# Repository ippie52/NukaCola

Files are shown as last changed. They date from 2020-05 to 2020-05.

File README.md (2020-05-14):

# NukaCola

## What is this for?
This is an Arduino Nano project aimed specifically for a more exciting display of a Fallout themed decoration. The code here is customised for my display, however could easily be adapted for other displays.

I have deliberately split the code into fairly logical files, however I have not bothered extracting the code into headers and source CPP files as my aim was to get this working, not present this to a customer with all the bells and whistles.

That being said, my occupation requires I be thorough with documentation and so it heavily commented, which will hopefully help anyone wishing to adapt this code for their own projects.

There are several 'features' that I would like to fix, but currently they don't cause any breakages, so they may never be changed.

## Hardware

### Bill of materials (electronics)
This is aimed at the Arduino Nano boards, and therefore the pin mappings may not be correct if you are using another platform.
As well as an Arduino Nano, I also used:
- Arduino Nano
- 6 x 5mm UV LEDs (For illuminating the bottle)
- 6 x 220 Ohm resistors (for the UV LEDs)
- 3 x Push to make switches (for changing the illumination)
- 3 x 10k Ohm resistors (pull-downs for the inputs)
- 3 x 3mm LEDs (for showing what settings are being updated)
- 3 x 330 Ohm resistors (for the display LEDs)
- Strip board

### Stand
I have placed the STL for the stand on [thingiverse](https://www.thingiverse.com/thing:4352918). I printed this using blue glow in the dark PLA, which works rather nicely. This was printed with the bottle in mind, where the 5mm UV LEDs are mounted to fit just under the base of the bottle, are evenly spaced at 60° from one another in a circle, and angled towards the water line within the bottle (around 7° off the vertical). Once printed, I also painted the logo on the front with white Acrylic, which blocks the light when showing to keep the logo visible.

For more info on the stand, please visit the link above.

### Bottle
The bottle used was an old 330ml Coca Cola bottle with a Nuka Cola Quantum label and bottle top printed and stuck on. The contents is tonic water (quinine fluoresces under UV light), with some blue curaçao for the blue tinge.

### Pin map
| Arduino Nano Pin | Connected To | Notes |
| ----- | --- | --- |
| 3 | Display LED 1 |  Display output (5mm UV LED with 220 Ohm resistor) |
| 5 | Display LED 2 |  Display output (5mm UV LED with 220 Ohm resistor) |
| 6 | Display LED 3 |  Display output (5mm UV LED with 220 Ohm resistor) |
| 9 | Display LED 4 |  Display output (5mm UV LED with 220 Ohm resistor) |
| 10 | Display LED 5 |  Display output (5mm UV LED with 220 Ohm resistor) |
| 11 | Display LED 6 |  Display output (5mm UV LED with 220 Ohm resistor) |
| 11 | Display LED 6 |  Display output (5mm UV LED with 220 Ohm resistor) |
| 2 | Mode LED | Indicator output for 'mode' (3mm LED with 330 Ohm resistor) |
| 4 | Speed LED | Indicator output for 'speed' (3mm LED with 330 Ohm resistor) |
| 7 | Brightness LED | Indicator output for 'brightness' (3mm LED with 330 Ohm resistor) |
| 8 | Setting Input | Input for changing the current setting mode |
| 12 | Up Input | Input for incrementing the current setting value |
| 13 | Down Input | Input for decrementing the current setting value |

## Patterns and speeds
There are several [illumination patterns](https://imgur.com/gallery/nqhQovs) that provide interesting effects. To obtain these effects, the LEDs are treated as being in a circle, with the first LED in the cluster being at 0°, then each other being evenly spaced (depending on the number of LEDs). With six LEDs, they are therefore at 60° from one another, i.e. 0°, 60°, 120°, 180°, 240° and 300°.

With the concept of a circle, the speed of the illumination pattern is effectively the number of revolutions around the circle per minute, ranging from 6 (once every ten seconds) to 60 (once per second). Different patterns appear better at different speeds, so play around until you find a nice combination.

Considering the speed, the time since the LED cluster was started can therefore determine the position around the circle and the current revolution. I call this the head or lead angle.

Image of wave pattern

### Just On
This is simple. The LEDs are just on at the brightness level set.

### Chase (Clockwise, Anticlockwise and Both)
For this pattern, the lead angle will be at the maximum brightness whilst one degree behind it will be off. This means the LED closest behind the lead angle will illuminate from off to full then dim slowly. This pattern is available clockwise, (LEDs 1 to 6) or anticlockwise (6 to 1), and both, where the lead angle is mirrored around 0° and 180°, giving two lead angles.

### Wave (Clockwise and Anticlockwise)
The brightness around the lead angle ramps up and down, with 180° being fully off. This causes the brightness to move around the circle in a wave, both clockwise and anticlockwise.

### Throb
The throb is a simple cosine wave of the current lead angle, with all LEDs being at the same brightness.

### Throb Two
This is similar to the previous, however provides a double pulse. Using a sine wave that is reflected around 180° there is a ramp up, back to half brightness, the back up to full. The pulse then drops to zero, back up to half brightness, then down to zero again before repeating the pattern. I found this by accident when messing up the equation, but I liked it so left it in.

### Heartbeat
This pattern is a rough attempt to look like a heartbeat.

### Raindrop
Each LED will flash at a random time once per revolution. The flash will be a sudden ramp up with slower drop down.

### Flames
This is supposed to look like flames flickering. It's not perfect and for some reason it always ends up on the low end of brightness, but it seems good enough for the purpose!

### Static/Noise
This is based on the flames pattern, but introduces additional spikes of noise which give a much more random pattern.

## Controls
### Manual controls
If using the buttons and LEDs attached to the board, the controls are fairly self explanatory:

#### Setting Button
When pressed, this should trigger the pattern mode LED to light up. Subsequent presses will then cause the brightness then speed LEDs to light up. When these mode LED indicators are lit, they indicate that the particular setting can be updated by pressing the up or down buttons. If no buttons are pressed for over 10 seconds, they LEDs will turn off and running or sleep more will continue.

Pressing the setting button for more than 2 seconds will toggle the mode from running to sleep mode. Pressing again for a further 2 seconds will put it back into running mode.

#### Up Button
When in pattern mode, this will select the next illumination pattern. This will always trigger a change as the patterns will loop. When in brightness mode, it will increase the brightness until it reaches 100%. When in speed mode, it will increase the speed until it reaches 100%.

#### Down Button
When in pattern mode, this will select the previous illumination pattern. This will always trigger a change as the patterns will loop. When in brightness mode, it will decrease the brightness until it reaches 5% (the lowest value permitted). When in speed mode, it will decrease the speed until it reaches 10% (the lowest speed permitted).

### Serial Comms
The API for this is fairly basic, allowing for simple strings to be used to set and alter values.

#### API Query
By sending the string "api?" (or any unrecognised command), a rough guide to the API will be sent via the serial connection.

#### Pattern
The letter 'P' is used to update the illumination pattern. Sending an upper case 'P' will increment the pattern, whilst a lower case will decrement it. To set a particular pattern index, use 'p=X', where X is the pattern index (the case of the 'p' is not important here)

#### Brightness
The letter 'B' is used to update the brightness value. Like with the pattern controls, an upper case 'B' will increase the brightness, whilst a lower case 'b' will decrease the brightness. The brightness level cannot be increased or decreased below the minimum and maximum values. To set the value exactly, use 'b=XXX', where XXX is the brightness percentage.

#### Speed
The letter 'S' is used to update the speed value. Like with the pattern and brightness controls, an upper case 'S' will increase the speed, whilst a lower case 'b' will decrease the speed. The speed level cannot be increased or decreased below the minimum and maximum values. To set the value exactly, use 's=XXX', where XXX is the speed percentage.

#### Sleep mode
To turn off the LED cluster, use the command 'X' (case insensitive).

#### Running mode
To bring the LED cluster out of sleep mode, use the command 'R' (case insensitive).

## How all this came to be
The Hallowe'en before last, I went with a Fallout themed costume. Along with that, I made a glowing Nuka Cola Quantum bottle and a little stand made from some strip board, a 9 volt battery, some resistors and UV LEDs.

Since then, it's been sat above my desk gathering dust.

I recently had reason to start looking at Arduino boards, and whilst doing so, looked up and thought about my Nuka Cola Quantum bottle. I also thought about how it would be nice to have a proper stand for it, and then decided to make it a reality.

I created a stand from blue glow in the dark PLA on my 3D printer and put together an Arduino Nano board to control the UV LEDs for a more exciting display.

Provides software and hardware for creating a fancy Nuka Cola bottle stand

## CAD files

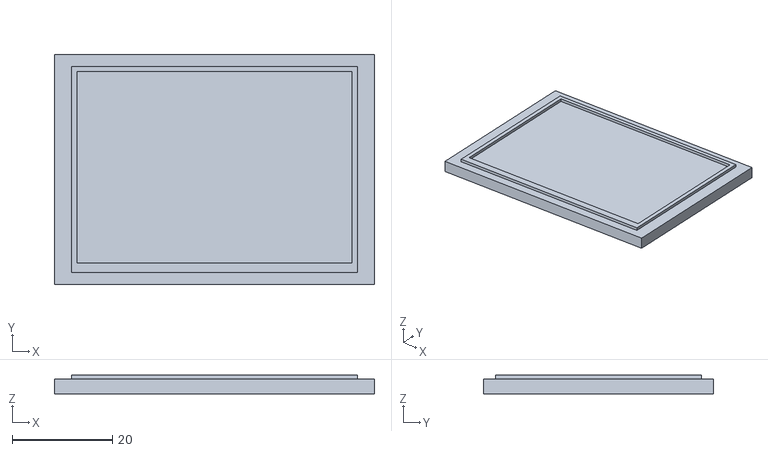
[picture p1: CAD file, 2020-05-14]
3D_files/ncq-blank-face-plate.stl
64.0 x 46.0 x 3.75

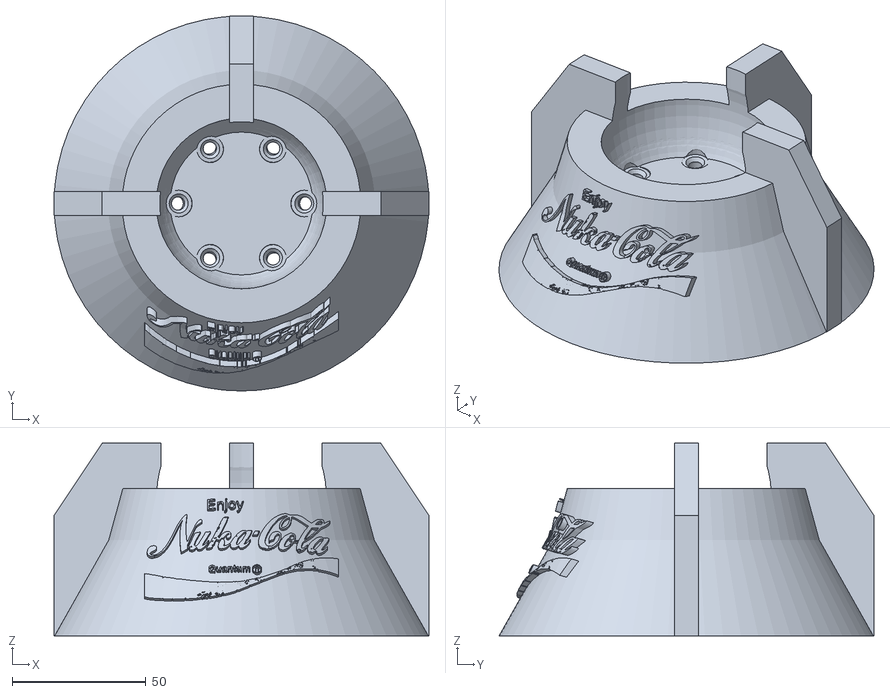
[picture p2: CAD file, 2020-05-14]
3D_files/ncq-stand-no-back-plate.stl
140.0 x 140.0 x 72.0

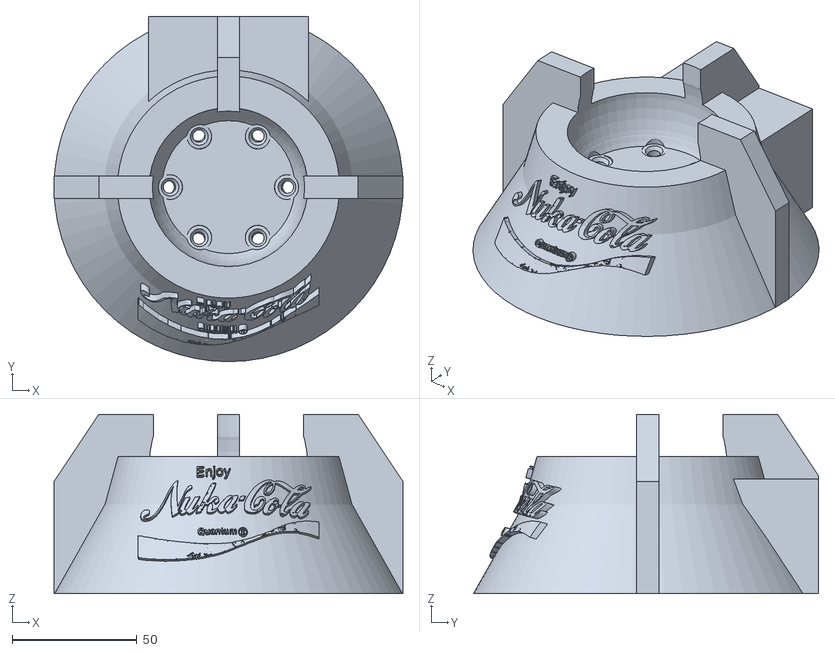
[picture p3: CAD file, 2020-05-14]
3D_files/ncq-stand-top.stl
140.0 x 138.5 x 72.0

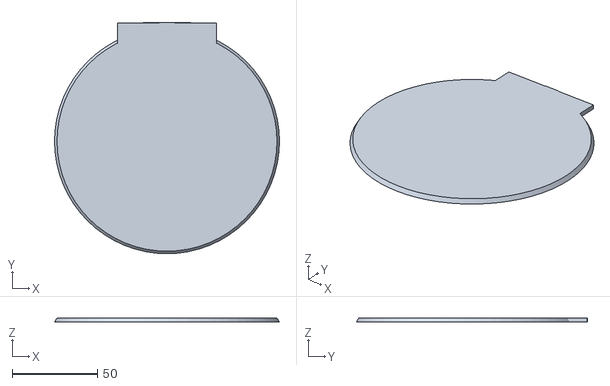
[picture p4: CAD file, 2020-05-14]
3D_files/ncq-base.stl
132.0 x 135.8 x 2.50

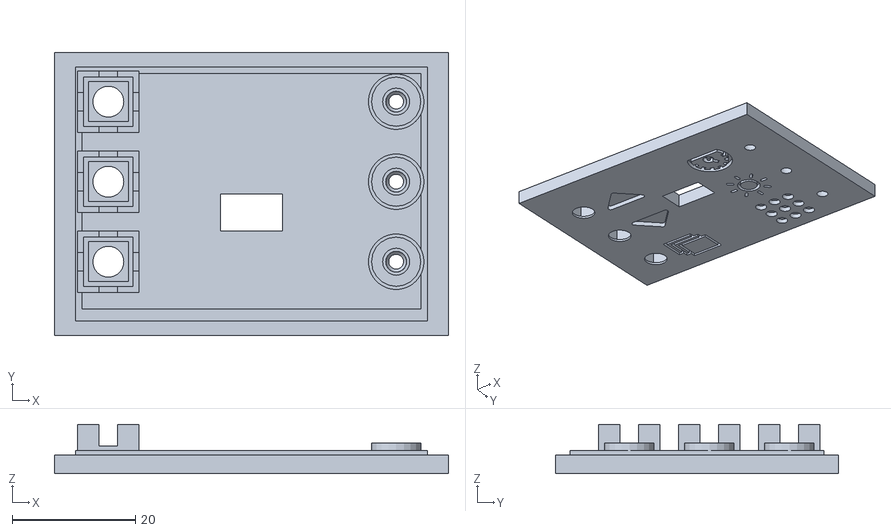
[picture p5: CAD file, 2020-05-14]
3D_files/ncq-face-plate.stl
64.0 x 46.0 x 8.00

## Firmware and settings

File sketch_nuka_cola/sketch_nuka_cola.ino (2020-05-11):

/**
 * @file    sketch_nuka_cola.ino
 *
 * @brief   Provides the top level control of the illuminated Nuka Cola stand.
 *
 * @author  Kris Dunning (ippie52@gmail.com)
 * @date    2020
 */
#include <string.h>
#include "Common.h"
#include "LedCluster.h"
#include "InputHelper.h"
#include "OutputHelper.h"

/**
 * Constants
 */

/// @brief  Serial input to increment the pattern.
#define PATTERN_MODE_CHAR       'P'
/// @brief  Serial input to increment the speed.
#define SPEED_MODE_CHAR         'S'
/// @brief  Serial input to increment the brightness.
#define BRIGHTNESS_MODE_CHAR    'B'
/// @brief  Serial input to set into running mode.
#define RUNNING_MODE_CHAR       'R'
/// @brief  Serial input to set into sleep mode.
#define SLEEP_MODE_CHAR         'X'
/// @brief  API request string.
#define API_REQUEST_STR         "api?"


/**
 * Forward declarations
 */
static void upBtnToggled(const int, const int state, const long);
static void downBtnToggled(const int, const int state, const long);
static void powerTimeout(const int, const long);
static void settingBtnToggled(const int, const int state, const long durationMs);

/// @brief  The available modes - used to identify what input signals do.
enum SettingModes
{
  Sleep,
  Running,
  Pattern,
  Brightness,
  Speed
};

/// @brief  Pointer to an LED cluster, used to create illumination patterns.
LedCluster *cluster = nullptr;

/// @brief  Up button input.
InputHelper upBtn(Pins::SettingUpBtn, upBtnToggled);
/// @brief  Down button input.
InputHelper downBtn(Pins::SettingDownBtn, downBtnToggled);
/// @brief  Settings/Mode selection input.
InputHelper settingSelectionBtn(
  Pins::SettingSelectionBtn,
  settingBtnToggled,
  powerTimeout,
  2000
);

/// @brief  The mode LED indicator.
OutputHelper modeLED(Pins::ModeLED);
/// @brief  The speed LED indicator.
OutputHelper speedLED(Pins::SpeedLED);
/// @brief  The brightness LED indicator.
OutputHelper brightnessLED(Pins::BrightnessLED);

/// @brief  The current mode.
SettingModes mode = SettingModes::Running;
/// @brief  Stores when the last mode change occurred.
long lastModeChange = 0;

/*******************************************************************************
 * @brief   Toggles the cluster value for the given setting mode.
 *
 * @param   delta   The value to be added for the current setting mode
 *
 * @return  The value saved by the cluster for the current mode.
 */
static int toggleClusterValue(const int delta)
{
  int value = 0;
  if (cluster != nullptr)
  {
    switch (mode)
    {
      case SettingModes::Pattern:
        lastModeChange = millis();
        value = cluster->updatePattern(delta);
        modeLED = LOW;
        delay(80);
        modeLED = HIGH;
        break;

      case SettingModes::Brightness:
        lastModeChange = millis();
        value = cluster->updateBrightness(delta);
        brightnessLED = LOW;
        delay(80);
        brightnessLED = HIGH;
        break;

      case SettingModes::Speed:
        lastModeChange = millis();
        value = cluster->updateSpeed(delta);
        speedLED = LOW;
        delay(80);
        speedLED = HIGH;
        break;

      case SettingModes::Running: // Deliberate fall-through
      case SettingModes::Sleep:   // Deliberate fall-through
      default:
        // Nothing to do
        break;
    }
  }
  return value;
}

/***************************************************************************
 * @brief   Handles the up button presses.
 *
 * @param   state  The current state of the button press
 */
static void upBtnToggled(const int, const int state, const long)
{
  if (state && cluster != nullptr)
  {
    toggleClusterValue(1);
  }
}

/***************************************************************************
 * @brief   Handles the down button presses.
 *
 * @param   state  The current state of the button press
 */
static void downBtnToggled(const int, const int state, const long)
{
  if (state && cluster != nullptr)
  {
    toggleClusterValue(-1);
  }
}

/***************************************************************************
 * @brief   Time-out function called when the settings/mode button has been
 *          pressed for a prolonged period of time. This will either put the
 *          LED cluster to sleep, or wake it up.
 */
static void powerTimeout(const int, const long)
{
  if (cluster != nullptr)
  {
    if (SettingModes::Sleep == mode)
    {
      mode = SettingModes::Running;
      cluster->startUp();
    }
    else if (SettingModes::Running == mode)
    {
      mode = SettingModes::Sleep;
      cluster->shutdown();
    }
  }
}

/***************************************************************************
 * @brief   Sets the current mode for input signals.
 *
 * @param   newMode  The new mode to change to
 */
static void setMode(const int newMode)
{
  mode = newMode;
  modeLED = SettingModes::Pattern == mode;
  brightnessLED = SettingModes::Brightness == mode;
  speedLED = SettingModes::Speed == mode;
  lastModeChange = millis();
}

/***************************************************************************
 * @brief   Handler for when the setting button is pressed.
 *
 * @param   state      The current state of the button
 */
static void settingBtnToggled(const int, const int state, const long)
{
  if (state && cluster != nullptr)
  {
    switch (mode)
    {
      case SettingModes::Pattern:
        setMode(SettingModes::Brightness);
        break;

      case SettingModes::Brightness:
        setMode(SettingModes::Speed);
        break;

      case SettingModes::Speed:
        setMode(SettingModes::Pattern);
        break;

      case SettingModes::Running:
        setMode(SettingModes::Pattern);

      case SettingModes::Sleep: // Deliberate fall-through
      default:
        break;
    }
  }
}

/*******************************************************************************
 * @brief   Sends the API to the connected serial device.
 */
static void sendApi()
{
  Serial.println("Letter in square brackets is the key.");
  Serial.println("Upper case increases, lower case decreases.");
  Serial.println("To assign value, use '=X' where X is the value to set.");
  Serial.println("Example: \"s=100\" sets Speed to 100%, and \"b\" decreases brightness one step.");
  Serial.print(String("Pattern [") + PATTERN_MODE_CHAR + "] ");
  for(int i = 0; i < Patterns::PATTERN_COUNT; i++)
  {
    Serial.print(String(PATTERN_STRINGS[i]) + " (" + i + "),");
  }
  Serial.println("");
  Serial.println(
    String("Speed [") + SPEED_MODE_CHAR +"] " +
    SpeedConstants::MIN_SPEED_PCT + "-" +
    SpeedConstants::MAX_SPEED_PCT
  );
  Serial.println(
    String("Brightness [") + BRIGHTNESS_MODE_CHAR + "] " +
    BrightnessConstants::MIN_BRIGHTNESS_PCT + "-" +
    BrightnessConstants::MAX_BRIGHTNESS_PCT
  );
  Serial.println(String("Running Mode [") + RUNNING_MODE_CHAR + "]");
  Serial.println(String("Sleep Mode [") + SLEEP_MODE_CHAR + "]");
}

/***************************************************************************
 * @brief   Gets the value assigned to the incoming command.
 *
 * @param   command  The command string
 * @param   chars    The number of characters in the command
 *
 * @return  The value if provided, otherwise zero.
 */
static int getIncomingValue(const char * const command, const size_t chars)
{
  const int offset = (command[0] == '=') ? 1 : 0;
  String value = "";
  for(int i = offset; i < chars; i++)
  {
    if (!isDigit(command[i]))
    {
      value = "0";
      break;
    }
    value += (char)command[i];
  }
  return value.toInt();
}

/***************************************************************************
 * @brief   Handles an incoming serial command.
 *
 * @param   command  The command to interpret
 * @param   chars    The number of characters in the command string
 */
static void handleSerialCommand(const char * const command, const size_t chars)
{
  const SettingModes currentMode = mode;
  if (cluster != nullptr && chars > 0)
  {
    const int compare = strncmp(command, API_REQUEST_STR, chars);
    if (strncmp(command, API_REQUEST_STR, strlen(API_REQUEST_STR)) == 0)
    {
      sendApi();
    }
    else
    {
      const char cmd = toupper(command[0]);
      const bool inc = cmd == command[0];
      const bool testValue = chars > 1;
      int newValue = 0;
      // For pattern, speed and brightness, if it looks like there's a value
      // provided, test for it, otherwise increment or decrement based on the
      // case of the command.
      switch (cmd)
      {
        case PATTERN_MODE_CHAR:
          {
            int pattern = 0;
            if (testValue)
            {
              newValue = getIncomingValue(command + 1, chars - 1);
              pattern = cluster->setPattern(newValue);
            }
            else
            {
              setMode(SettingModes::Pattern);
              pattern = toggleClusterValue(inc ? 1 : -1);
              setMode(currentMode);
            }
            Serial.println(String(PATTERN_MODE_CHAR) + "=" + pattern);
          }
          break;

        case SPEED_MODE_CHAR:
          {
            int speed = 0;
            if (testValue)
            {
              newValue = getIncomingValue(command + 1, chars - 1);
              speed = cluster->setSpeedPercent(newValue);
            }
            else
            {
              setMode(SettingModes::Speed);
              speed = LedCluster::toSpeedPercentage(toggleClusterValue(inc ? 1 : -1));
              setMode(currentMode);
            }
            Serial.println(String(SPEED_MODE_CHAR) + "=" + speed);
          }
          break;

        case BRIGHTNESS_MODE_CHAR:
          {
            int brightness = 0;
            if (testValue)
            {
              newValue = getIncomingValue(command + 1, chars - 1);
              brightness = cluster->setBrightnessPercent(newValue);
            }
            else
            {
              setMode(SettingModes::Brightness);
              brightness = LedCluster::toBrightnessPercentage(toggleClusterValue(inc ? 1 : -1));
              setMode(currentMode);
            }
            Serial.println(String(BRIGHTNESS_MODE_CHAR) + "=" + brightness);
          }
          break;

        case RUNNING_MODE_CHAR:
          setMode(SettingModes::Running);
          cluster->startUp();
          Serial.println(RUNNING_MODE_CHAR);
          break;

        case SLEEP_MODE_CHAR:
          setMode(SettingModes::Sleep);
          cluster->shutdown();
          Serial.println(SLEEP_MODE_CHAR);
          break;

        default:
          Serial.println(String("Unknown command: ") + command);
          sendApi();
          break;
      }
    }
  }
}

/*******************************************************************************
 * @brief   Check for serial connection and any incoming requests.
 */
static void pollSerial()
{
  if (Serial)
  {
    const size_t available = Serial.available();
    if (available != 0)
    {
      char *command = new char[available + 1];
      Serial.readBytes(command, available);

      // Strip new line
      if (command[available - 1] == '\n')
      {
        command[available - 1] = '\0';
      }
      else
      {
        command[available] = '\0';
      }
      handleSerialCommand(command, strlen(command));
      delete[] command;
      command = nullptr;
    }
  }
}

/*******************************************************************************
 * @brief   Sets up the required global variables and communications.
 */
void setup()
{
  Serial.begin(9600);
  byte ledPins[] = {
    Pins::DisplayLED1,
    Pins::DisplayLED2,
    Pins::DisplayLED3,
    Pins::DisplayLED4,
    Pins::DisplayLED5,
    Pins::DisplayLED6
  };

  cluster = new LedCluster(ledPins, 6);

  // Seed the randomiser with the current noise on analogue input zero
  randomSeed(analogRead(0));
}

/*******************************************************************************
 * @brief   Loop function, runs continually.
 */
void loop()
{

  pollSerial();
  // Check the inputs for any changes
  upBtn.poll();
  downBtn.poll();
  settingSelectionBtn.poll();

  // Update the LED cluster levels
  cluster->poll();

  // If the speed, brightness or pattern is currently being changed, time out
  // after a certain time, back into running mode and turn off the setting LEDs
  if (mode != SettingModes::Running && mode != SettingModes::Sleep)
  {
    const long delta = millis() - lastModeChange;
    if (delta > 10000)
    {
      setMode(SettingModes::Running);
      lastModeChange = 0;
    }
  }
}

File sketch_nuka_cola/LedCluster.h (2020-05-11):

/**
 * @file    LedCluster.h
 *
 * @brief   Provides the LedCluster class, which can be used to draw patterns
 *          with a given collection of LEDs.
 *          When creating patterns, this class uses the concept of a circle, or
 *          more appropriately, the angle of a point orbiting around along the
 *          circle. The head or lead of the circle is the focal point. For most
 *          patterns, this will be the brightest point. Others simply use this
 *          as the amount of time within the current revolution.
 *
 * @author  Kris Dunning (ippie52@gmail.com)
 * @date    2020
 */
#pragma once
#include <string.h>
#include "NonVol.h"

/**
 * Constants
 */

/// @brief  The settings version number.
#define VERSION     (1)

/// @brief  The minimum settle time for setting the LED PWM values.
static const long MIN_SETTLE_TIME = 20;

/// @brief  This look up table provides the brightness as a whole percentage
///         to the equivalent 8-bit duty cycle. As apparent brightness is more
///         logarithmic than linear, the values here show a logarithmic
///         increase. It's also worth noting that there are 101 values, from
///         zero to one hundred inclusive.
static const byte BRIGHTNESS_TO_DUTY_CYCLE[] =
{
   0,   1,   2,   3,   4,   5,   6,   7,   8,   9,
  10,  12,  13,  14,  15,  16,  17,  18,  20,  21,
  22,  23,  24,  26,  27,  28,  30,  31,  32,  33,
  35,  36,  38,  39,  40,  42,  43,  45,  46,  48,
  49,  51,  53,  54,  56,  57,  59,  61,  63,  64,
  66,  68,  70,  72,  74,  76,  78,  80,  82,  84,
  86,  88,  90,  93,  95,  97, 100, 102, 105, 107,
 110, 113, 116, 118, 121, 124, 128, 131, 134, 137,
 141, 145, 148, 152, 156, 160, 165, 169, 174, 179,
 184, 189, 195, 201, 207, 214, 221, 229, 237, 245, 255
};

/**
 * Forward declarations.
 */
class LedCluster;

/**
 * Structures, enumerations and type definitions.
 */

/// @brief  Provides the available LED illumination patterns.
enum Patterns
{
    JustOn,
    // Chasing - The lead LED comes on at full brightness,
    // and dims as the head of the circle moves around
    ChaseClockwise,
    ChaseAntiClockwise,
    ChaseBoth,
    // The peak of the circle is brightest, with the area surrounding it
    // dimming gently to nothing at 180 degrees away
    WaveClockwise,
    WaveAntiClockwise,
    // The lights all throb from off to on
    Throb,
    // Another throb mode with some flicker
    Throb2,
    // Heart beat effect, two pulses per revolution
    Heartbeat,
    // Each light randomly lights up quickly then fades once per revolution
    Raindrop,
    // Rough attempt at a candle flicker
    Flames,
    // Fairly random flickering
    Static,

    PATTERN_COUNT
};

/// @brief  Strings for each pattern available.
const String PATTERN_STRINGS[Patterns::PATTERN_COUNT] =
{
    "Just On",
    "Chase Clockwise",
    "Chase AntiClockwise",
    "Chase Both",
    "Wave Clockwise",
    "Wave AntiClockwise",
    "Throb",
    "Throb Two",
    "Heartbeat",
    "Raindrop",
    "Flames",
    "Static",
};

/// @brief  The settings object, stored in non-volatile memory so that the
///         settings persist between power cycles.
struct Settings
{
    // The version number - This changes if the settings layout change
    int version;
    // The last selected illumination pattern
    Patterns pattern;
    // Multiplier used to set the maximum brightness
    int brightnessMultiplier;
    // The speed of the illumination patterns determined by how many revolutions
    // per minute around the "circle".
    int revsPerMinute;
    // Unwritten EEPROM bytes are all 0xFF. This boolean value will help identify
    // when a fresh read is done. It will not protect against structure changes.
    byte invalid;
};

/// @brief  Information representing the current position of the "lead" point
///         of the circle during a revolution.
struct LightLocationInfo
{
    // The current angle in degrees
    float angle;
    // The revolution number, good for identifying when a new cycle has started
    long revolution;
};

/// @brief  Information about each LED, allowing different illumination patterns
///         to be carried out.
struct LedInfo
{
    int index;
    float angle;
    int brightness;
    int pin;
    int extra;
};

/// @brief  Type definition for an illumination pattern method.
typedef void (LedCluster::*PatternMethod)
(
    LedInfo * const,
    const LightLocationInfo * const
);

/// @brief  Constants required for calculating the current brightnesses of
///         LEDs. These will be used to add a range to the maximum brightness
///         of the LEDs, such that they can be turned down if needs be.
enum BrightnessConstants
{
    // The minimum brightness level
    MIN_BRIGHTNESS = 1,
    // Maximum brightness level
    MAX_BRIGHTNESS = 20,
    // The divider to be applied to the current brightness level
    BRIGHTNESS_DIVIDER = MAX_BRIGHTNESS,
    // The default brightness level on a clean upload
    DEFAULT_BRIGHTNESS = 18,
    // The minimum brightness percentage
    MIN_BRIGHTNESS_PCT = ((100 * MIN_BRIGHTNESS) / MAX_BRIGHTNESS),
    // The maximum brightness percentage
    MAX_BRIGHTNESS_PCT = 100,

};

/// @brief  Constants required for calculating the speed of the illumination
///         pattern changes.
enum SpeedConstants
{
    // Minimum speed level (in revolutions per minute)
    MIN_SPEED = 6,
    // Maximum speed level (in revolutions per minute)
    MAX_SPEED = 60,
    // The number of speed levels to increase by per step
    SPEED_STEP = 3,
    // The default speed on a clean upload
    DEFAULT_SPEED = 18,
    // The minimum speed percentage
    MIN_SPEED_PCT = ((100 * MIN_SPEED) / MAX_SPEED),
    // The maximum speed percentage
    MAX_SPEED_PCT = 100,
};

/// @brief  Constants required to create a raindrop effect.
enum RaindropConstants
{
    // The number of degrees the raindrop will appear over
    RAINDROP_ANGLE = 12,
    // The number of degrees the raindrop will take to brighten
    RAMPUP_ANGLE = 3,
    // The number of degrees the raindrop will fade over
    RAMPDOWN_ANGLE = RAINDROP_ANGLE - RAMPUP_ANGLE
};
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

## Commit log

2020-05-07 Initial commit
    Here lies some code thrown together over some crazy testing.
    It needs a lot of documentation and tidying.
    I have used some files that I created for another project.
    Do not use raindrop mode if you suffer from epilepsy.
    [LedLUT.xlsx, Patterns.xlsx]
2020-05-07 Add static (noise) mode
    This piggy-backs off the candle mode.
    [LedCluster.h]
2020-05-07 Tidy and comment the LedCluster class
2020-05-07 Tidy the arduino sketch code
2020-05-11 Update patterns spreadsheet
    [Patterns.xlsx]
2020-05-11 Fix up issues from review
    This commit contains fixes noticed on Github. It also includes an update
    to the patterns spreadsheet and some changes to the documentation to
    explain the pattern options.
    Additionally, the throb pattern has been simplified a little.
    [Patterns.xlsx]
2020-05-14 Add STL (3D print) files
    [ncq-base.stl, ncq-blank-face-plate.stl, ncq-face-plate.stl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]
